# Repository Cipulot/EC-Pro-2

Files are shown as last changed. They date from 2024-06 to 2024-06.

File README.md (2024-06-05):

# EC Pro2

Open source HHKB Pro2 Controller and mainboard.

## **DEPRECATED**

Project deprecated in favor of the EC Pro X.

Please note that no further support will be provided, let alone give support for boards not sourced from my official runs or approved sources.

# EC PRO X Available for direct purchase!

If you want to buy directly and support my work you can now do it so [here](https://cannonkeys.com/products/cipulot-ec-pcbs-and-daughterboards).

## Introduction

This project is a continuation of my development of open source EC boards.

The supported layout options are the following:

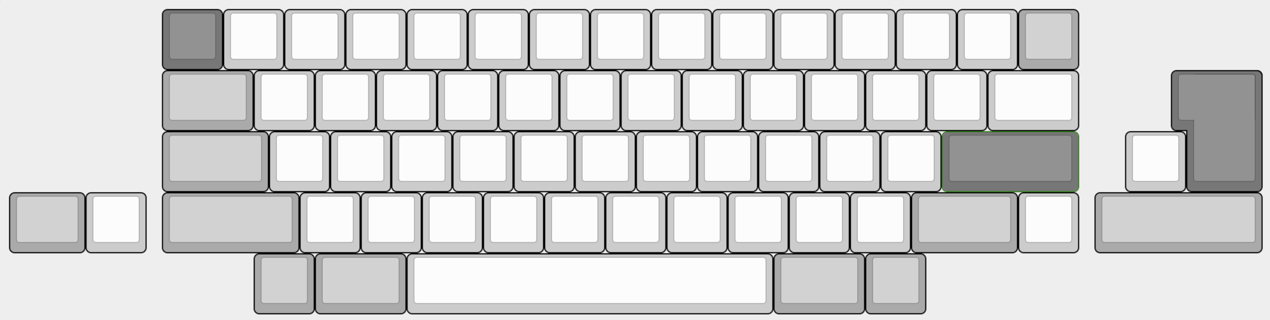
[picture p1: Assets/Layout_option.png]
Layout option


## Technical information

### Mainboard

- Layout size: HHKB Pro2 ANSI and some additions
- Compatible switches: EC switches (Topre and NIZ)
- Microcontroller: STM32F401
- Connector: JST connector for controller board
- Firmware compatibility: QMK (with VIA/VIAL support)
- Protection hardware (present on both the mainboard and both controller versions):
  - Fused
  - ESD protection

### Lite Controller board

The Lite controller board is a slimmed down version of the controller board, featuring only protection hardware and a JST connector for the mainboard.

This is cost effective choice in case the user doesn't need the USB hub feature or the aftermarket case doesn't take advantage of it.

### Normal Controller board

The Normal Controller instead is a full featured controller board, featuring a USB hub, a JST connector for the mainboard and a USB Type-C connector for the PC.

The USB hub is a USB 2.0 hub, featuring 3 USB-A 2.0 ports, one of which is internal, to be used for dongles or small USB drives.

Key features of the Normal Controller are:

- USB 2.0 hub based on the FE1.1 IC
- 2x USB-A 2.0 ports in the same position as the original HHKB Pro 2
- 1x internal USB-A 2.0 port
- Per port current limit on each downstream port using MIC2026-2 for the 2 externally accessible USB ports.

**NOTES**

- The internal USB port is intended only for low power devices, such as dongles and small usb drives as previously mentioned. It is not intended for high power devices. Furthermore it is not ESD protected nor current limited and shares the power rail with the rest of the controller.

- The main USB-C port, as well as the 2x externally accessible USB-A downstream ports are ESD protected and current limited.

Keep in mind the the USB 2.0 power budget sets a typical current limit of **500mA**, therefore that is the total budget available to the entire board (controller + mainboard + devices connected to the hub).

## Renders and Prototypes

### Render

Mainboard:

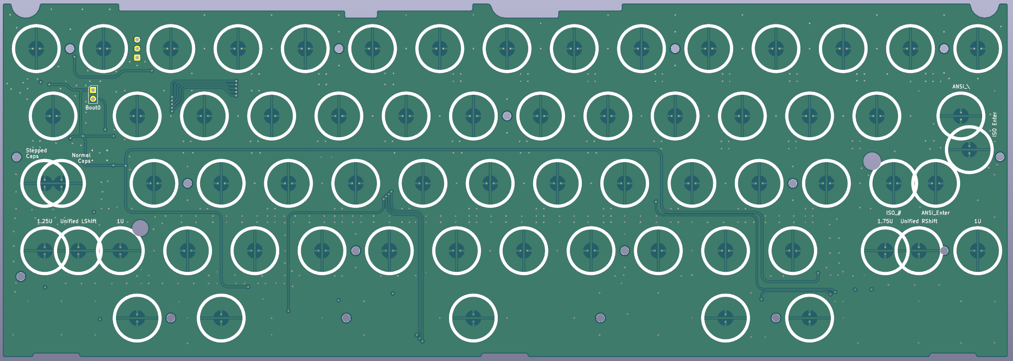
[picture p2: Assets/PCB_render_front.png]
PCB Front Render


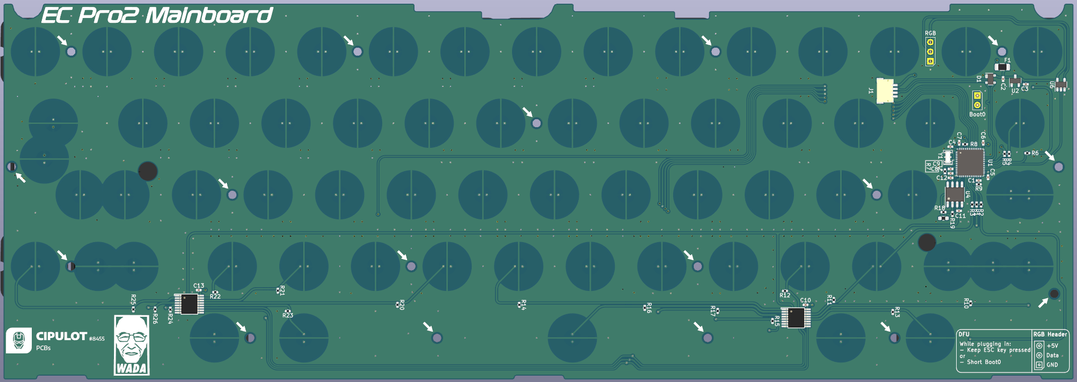
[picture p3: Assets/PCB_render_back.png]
PCB Back Render


Lite Controller board:
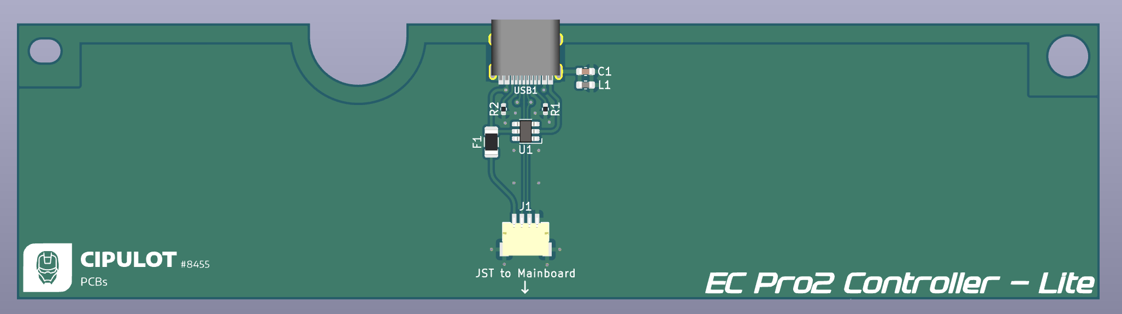
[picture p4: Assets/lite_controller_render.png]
Lite Controller Render


Normal Controller board:
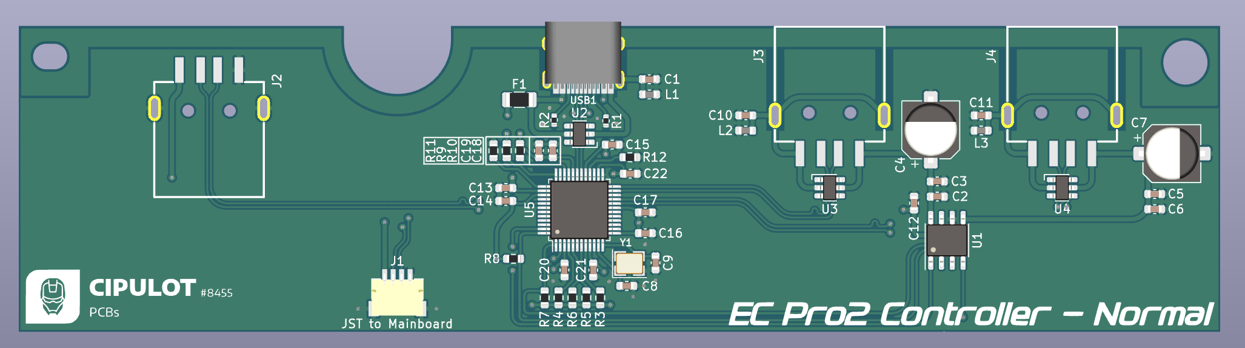
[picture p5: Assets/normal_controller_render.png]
Normal Controller Render


### Prototypes

Mainboard:

PCB Front

PCB Back

Lite Controller:
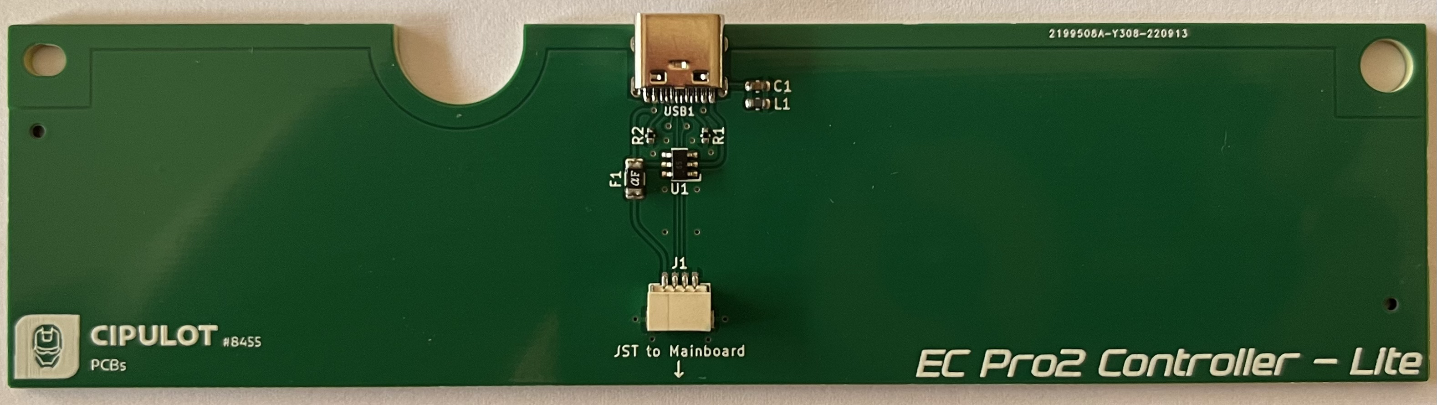
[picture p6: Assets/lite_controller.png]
Lite Controller


Normal Controller:
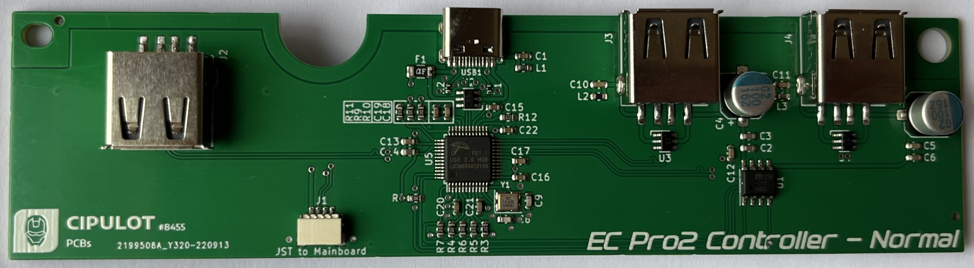
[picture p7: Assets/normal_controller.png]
Normal Controller


## Revisions and relative features

### Rev1

This revision implements all the main features of the mainboard ad controllers mentioned in the specifications.

#### Connectivity

The Revision 1 (Rev1) implements a USB hub based on the FE1.1 USB HUB IC.

Connection to the PC is achieved through a USB-C connector while devices downstream will use USB-A ports.

Mind that the USB-C connector is wider than the original USB mini connector used, therefore modifications to enlarge the port cutout on the case will be needed. In case you will use this board in an aftermarket case already designed with USB-C in mind n o further modifications are needed.

#### RGB header

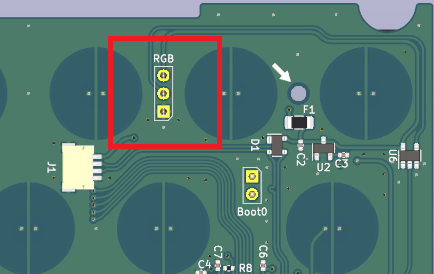
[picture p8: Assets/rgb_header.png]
RGB header


The mainboard features an RGB header for connecting +5V addressable RGB strips. THe properties of the lihting can be controlled through Vial or by assigning RGB control keycodes on the board itself.

On the bottom right corner of the PCB, near the bootloader instructions, a pinout diagram shows how to connect the strip to the header:

RGB legend

#### DFU

To access the DFU mode of the mainboard you can perform one of the following actions:

- press the key to which the `QK_BOOT` keycode is assigned (if available)
- while plugging in the board keep the `ESC` (top left corner key) pressed
- while plugging in the board short the `Boot0` pins on the mainboard

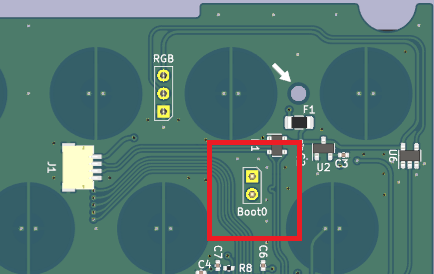
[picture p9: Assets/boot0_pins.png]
Boot0 pins


## PCB order procedure

In order to have me highers compatibility possible with PCB manufacturers, I decided to design the board around the [JLC7628 Stackup](https://cart.jlcpcb.com/impedance#:~:text=4%2DLayer%20Impedance%20Control%20Stackup) from JLCPCB.

The rational behind this is that the JCPCB stackup is relatively cheap and if the board worked with the stackup, it would be easier to get the board to work with pretty much any other many that offer an equivalent stackup and higher prices.

Both the `Lite` and `Normal` controllers can be instead be ordered with standard 2 layer stackup.

### Production files

The production can be found in the [Production folder](/Production).

As usual the `*.zip` files are the gerber files, `BOM-*.csv` are the BOM (Bill Of Material) files and `POS-*.csv` are the POS/CPL (Footprint POSition/Component Placement List) files.

## Mainboard

As mentioned above, the mainboard is designed around the JLCPCB stackup. The mainboard is a 4 layer board.

Here are the options to select when ordering the mainboard:

- PCB thickness: 1.6mm
- Impedance: NO
- Layer stackup:
  - L1(Top layer): `EC_Pro2_Mainboard-F_Cu.gbr`
  - L2(Inner layer1): `EC_Pro2_Mainboard-In1_Cu.gbr`
  - L3(Inner layer2): `EC_Pro2_Mainboard-In2_Cu.gbr`
  - L4(Bottom layer): `EC_Pro2_Mainboard-B_Cu.gbr`
- PCB Color: whatever you like
- Surface Finish: whatever you like
- Material Type: `FR-4 TG155`

All the other options can be left as default.

### Assembly options

Here follows the options to be used for assembly:

- Assembly Side: Bottom
- Tooling holes: `Added by JLCPCB`
- Confirm Parts Placement: `yes`

**USB-A connector**

An alternative part that has been tested and works is the `JINJIA USB-SMT-04F-S1-B1-R11` from [LCSC](https://www.lcsc.com/product-detail/USB-Connectors_JINJIA-USB-SMT-04F-S1-B1-R11_C718023.html).

As a general rule of thumb the USB-A connectors are interchangeable if they meet the following requirmemnts:

- fits the PCB outline
- has the same number of pins and mounting
- has the following receptor configuration

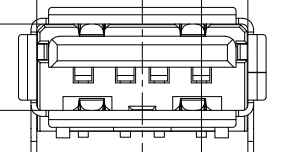
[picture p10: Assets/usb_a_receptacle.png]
USB-A receptacle
  

  To be more specific, the plastic part of the connector should be on the top and not the bottom.

  **BEWARE** that some USB-A connectors have the plastic part on the bottom, in this case the connector will have the pinout reversed, therefore causing inverse polarity on the USB lines.
  The following picture shows the correct orientation of the USB-A connector on the top board while the incorrect one on the bottom board:

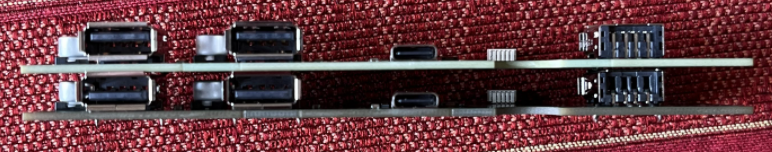
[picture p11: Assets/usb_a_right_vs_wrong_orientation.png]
USB-A orientation
  

### NOTES ABOUT THE OPTIONS

- Once you upload the gerber files wait for the system to automatically recognize the board outline and layers. It will take a while, be patient.

- `PCB thickness` has been tested on both 1.6mm and 1.2mm so it's your call on which one to use.

- For `Material Type` I strongly suggest to use `FR-4 TG155`, using the standard `FR4-Standard TG130-140` material might result in the board delamination and generally is not advised on 4 layer boards.

## Compatibility notice

The EC Pro2 project is intended as a full replacement kit for the OEM HHKB Pro2 controller and main PCB. Therefore it **IS NOT** compatible with the OEM PCBs (both controller and mainboard).

## Copyright notice

This project is not endorse nor sponsored in any way by Topre Corporation and PFU Limited. The HHKB Logo and Topre logo are trademarks of their respective owners.

## License

<br />This work is licensed under a <a rel="license" href="http://creativecommons.org/licenses/by-nc-sa/4.0/">Creative Commons Attribution-NonCommercial-ShareAlike 4.0 International License</a>.

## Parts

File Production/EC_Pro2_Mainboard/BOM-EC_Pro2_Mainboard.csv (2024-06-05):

Comment | Designator | Footprint | LCSC
1k | R19 | R_0402_1005Metric | C11702
STM32F401CBUx | U1 | QFN-48-1EP_7x7mm_P0.5mm_EP5.6x5.6mm | C118825
OPA350 | U4 | SOIC-8_3.9x4.9mm_P1.27mm | C13388
JST | J1 | JST-SR-4 | C145956
220p | C11 | C_0402_1005Metric | C1530
4.7u | C1 | C_0402_1005Metric | C23733
100 | R1,R2,R3,R4,R6 | R_0402_1005Metric | C25076
100k | R10,R11,R12,R13,R14,R15,R16,R17,R18,R20,R21,R22,R23,R24,R25,R26,R5 | R_0402_1005Metric | C25741
10k | R7,R8,R9 | R_0402_1005Metric | C25744
PRTR5V0U2X | D1 | SOT-143 | C2827688
100n | C10,C12,C13,C4,C5,C6,C7,C8 | C_0402_1005Metric | C307331
1u | C2,C3,C9 | C_0402_1005Metric | C52923
XC6206PxxxMR | U2 | SOT-23 | C5446
74HC4051 | U3,U5 | TSSOP16 | C5645
500mA | F1 | Fuse_1206_3216Metric | C70076
SN74AHCT1G125 | U6 | SOT-23-5 | C7484
8 MHz | Y1 | Resonator_SMD_Murata_CSTxExxV-3Pin_3.0x1.1mm | C907975

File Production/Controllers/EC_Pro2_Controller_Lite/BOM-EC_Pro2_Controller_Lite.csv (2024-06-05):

Comment | Designator | Footprint | LCSC
JST | J1 | JST-SR-4 | C145956
100n | C1 | C_0603_1608Metric | C14663
HRO-TYPE-C-31-M-12 | USB1 | HRO-TYPE-C-31-M-12-Assembly | C165948
5.1k | R1,R2 | R_0402_1005Metric | C25905
500mA | F1 | Fuse_1206_3216Metric | C70076
SRV05-4 | U1 | SOT-23-6-routable | C85364
220 @ 100MHz, 2A | L1 | L_0603_1608Metric | C85832

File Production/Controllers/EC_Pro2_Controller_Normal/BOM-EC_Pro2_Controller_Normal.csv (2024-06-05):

Comment | Designator | Footprint | LCSC
2.7K | R12 | R_0603_1608Metric | C13167
100u | C4,C7 | CP_Elec_6.3x5.9 | C134878
JST | J1 | JST-SR-4 | C145956
100n | C1,C10,C11,C12,C16,C17,C18,C19,C2,C20,C21,C22,C5 | C_0603_1608Metric | C14663
MIC2026-2BM | U1 | SOIC-8_3.9x4.9mm_P1.27mm | C148072
1u | C13 | C_0603_1608Metric | C15849
30p | C8,C9 | C_0603_1608Metric | C1658
HRO-TYPE-C-31-M-12 | USB1 | HRO-TYPE-C-31-M-12-Assembly | C165948
10u | C14,C15,C3,C6 | C_0603_1608Metric | C19702
10k | R10,R11,R3,R4,R5,R6,R7,R8,R9 | R_0603_1608Metric | C25804
5.1k | R1,R2 | R_0402_1005Metric | C25905
FE1.1 | U5 | LQFP-48_7x7mm_P0.5mm | C28958
500mA | F1 | Fuse_1206_3216Metric | C70076
USB_A | J2,J3,J4 | USB-SMT-04F-S1-B1-R9A | C718022
SRV05-4 | U2,U3,U4 | SOT-23-6-routable | C85364
220 @ 100MHz, 2A | L1,L2,L3 | L_0603_1608Metric | C85832
12MHz | Y1 | Crystal_SMD_3225-4pin_3.2x2.5mm | C9002

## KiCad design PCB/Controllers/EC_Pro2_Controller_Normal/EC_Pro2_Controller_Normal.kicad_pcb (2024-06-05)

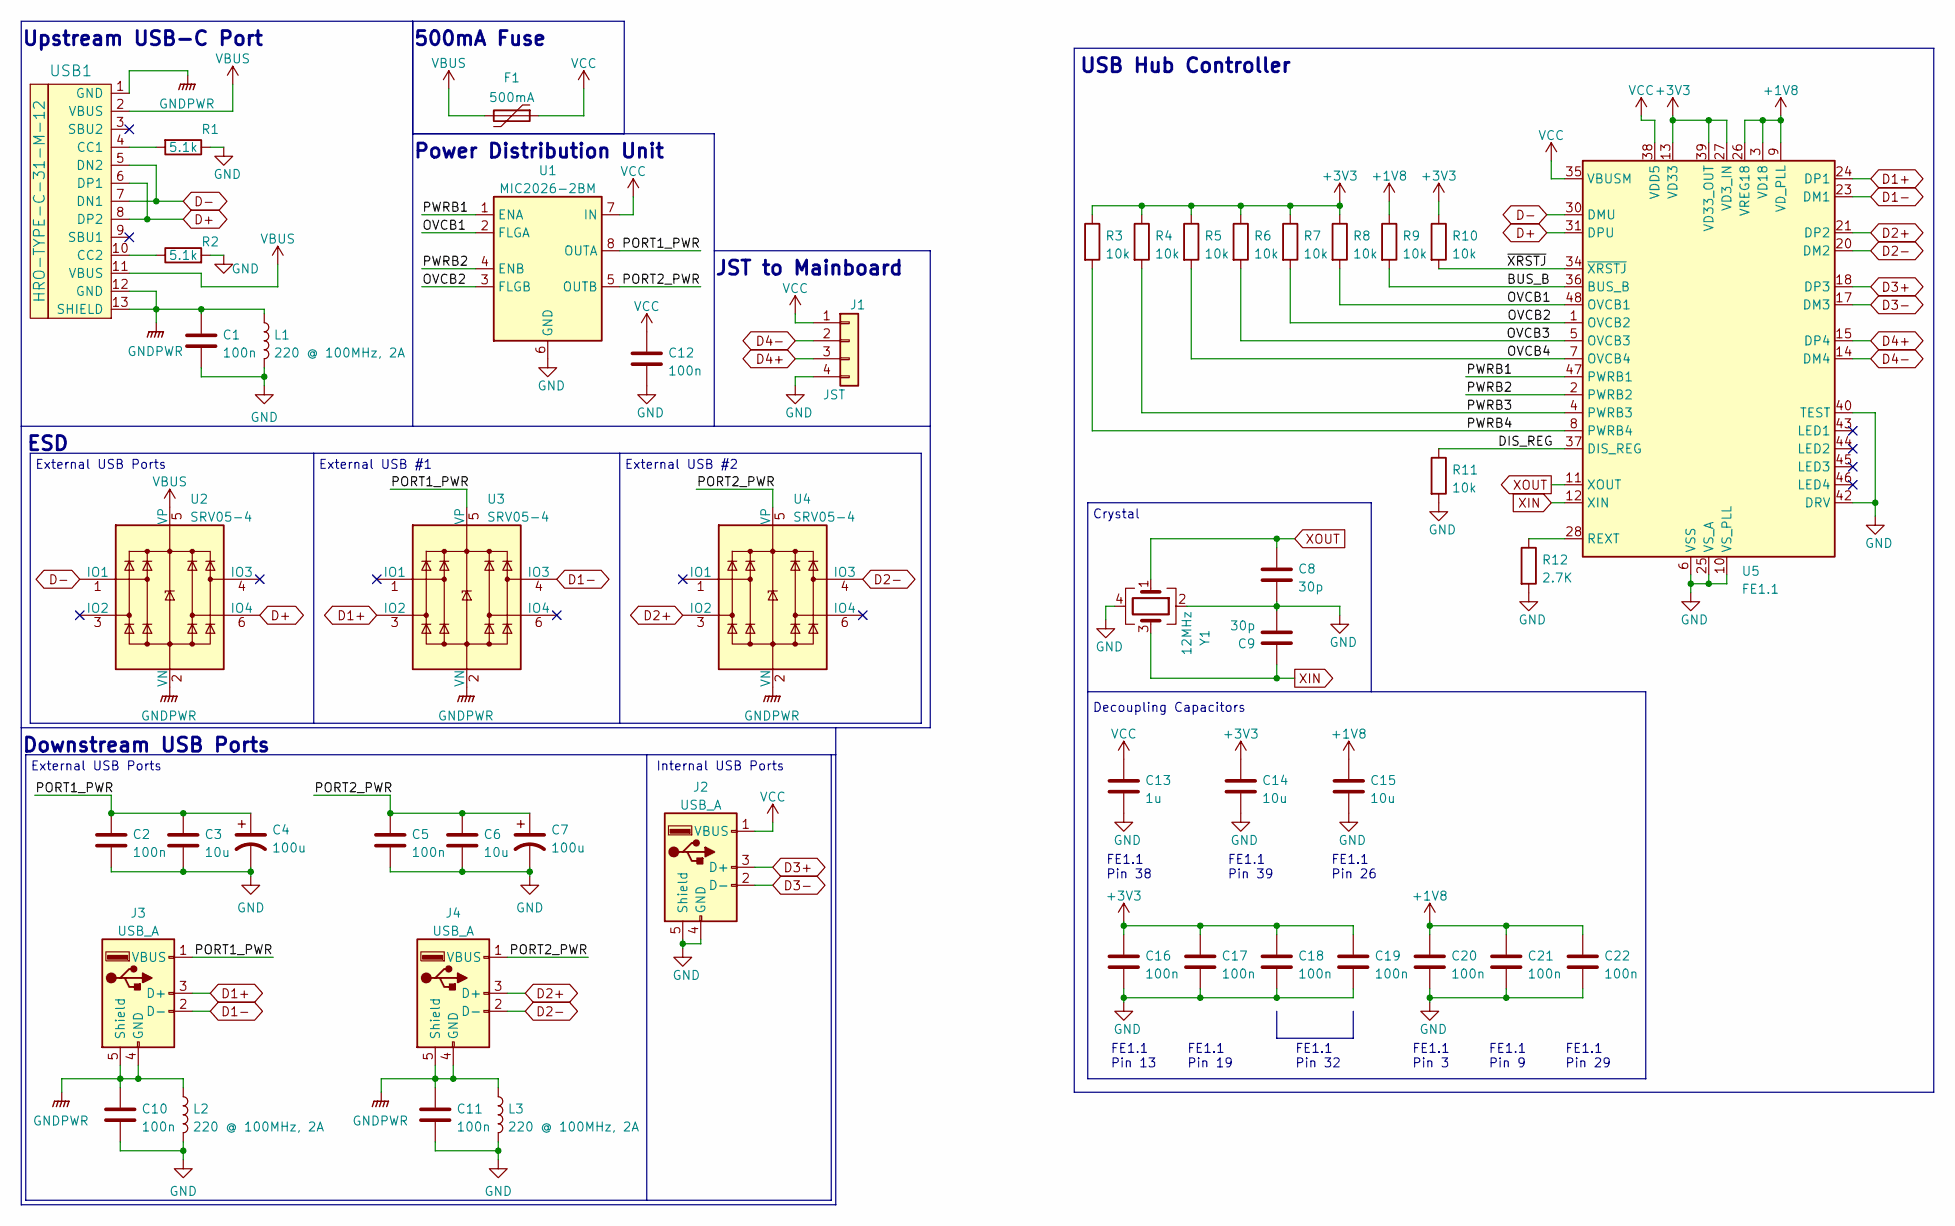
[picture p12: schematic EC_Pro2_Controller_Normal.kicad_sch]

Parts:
C1, C2, C5, C10, C11, C12, C16, C17, C18, C19, C20, C21, C22: 100n; C_0603_1608Metric; LCSC C14663
C3, C6, C14, C15: 10u; C_0603_1608Metric; LCSC C19702
C4, C7: 100u; CP_Elec_6.3x5.9; LCSC C134878
C8, C9: 30p; C_0603_1608Metric; LCSC C1658
C13: 1u; C_0603_1608Metric; LCSC C15849
F1: 500mA; Fuse_1206_3216Metric; LCSC C70076
J1: JST; JST-SR-4; LCSC C145956
J2, J3, J4: USB_A; USB-SMT-04F-S1-B1-R9A; LCSC C718022
L1, L2, L3: 220 @ 100MHz, 2A; L_0603_1608Metric; LCSC C85832
R1, R2: 5.1k; R_0402_1005Metric; LCSC C25905
R3, R4, R5, R6, R7, R8, R9, R10, R11: 10k; R_0603_1608Metric; LCSC C25804
R12: 2.7K; R_0603_1608Metric; LCSC C13167
U1: MIC2026-2BM; SOIC-8_3.9x4.9mm_P1.27mm; LCSC C148072
U2, U3, U4: SRV05-4; SOT-23-6-routable; LCSC C85364
U5: FE1.1; LQFP-48_7x7mm_P0.5mm; LCSC C28958
USB1: HRO-TYPE-C-31-M-12; HRO-TYPE-C-31-M-12-Assembly; LCSC C165948
Y1: 12MHz; Crystal_SMD_3225-4pin_3.2x2.5mm; LCSC C9002

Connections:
+1V8: C15.1, C20.1, C21.1, C22.1, R9.1, U5.3 (VD18), U5.9 (VD_PLL), U5.26 (VREG18), U5.29 (VD18)
+3V3: C14.1, C16.1, C17.1, C18.1, C19.1, R3.1, R4.1, R5.1, R6.1, R7.1, R8.1, R10.1, U5.13 (VD33), U5.19 (VD33), U5.27 (VD3_IN), U5.32 (VD33), U5.39 (VD33_OUT), U5.41 (VD33)
/BUS_B: R9.2, U5.36 (BUS_B)
/DIS_REG: R11.1, U5.37 (DIS_REG)
/OVCB1: R8.2, U1.2 (FLGA), U5.48 (OVCB1)
/OVCB2: R7.2, U1.3 (FLGB), U5.1 (OVCB2)
/OVCB3: R6.2, U5.5 (OVCB3)
/OVCB4: R5.2, U5.7 (OVCB4)
/PORT1_PWR: C2.1, C3.1, C4.1, J3.1 (VBUS), U1.8 (OUTA), U3.5 (VP)
/PORT2_PWR: C5.1, C6.1, C7.1, J4.1 (VBUS), U1.5 (OUTB), U4.5 (VP); also elsewhere on the board
/PWRB1: U1.1 (ENA), U5.47 (PWRB1)
/PWRB2: U1.4 (ENB), U5.2 (PWRB2)
/PWRB3: R4.2, U5.4 (PWRB3)
/PWRB4: R3.2, U5.8 (PWRB4)
/~XRSTJ: R10.2, U5.34 (~XRSTJ)
D1+: J3.3 (D+), U3.3 (IO2), U5.24 (DP1)
D1-: J3.2 (D-), U3.4 (IO3), U5.23 (DM1)
D2+: J4.3 (D+), U4.3 (IO2), U5.21 (DP2); also elsewhere on the board
D2-: J4.2 (D-), U4.4 (IO3), U5.20 (DM2); also elsewhere on the board
D3+: J2.3 (D+), U5.18 (DP3)
D3-: J2.2 (D-), U5.17 (DM3)
D4+: J1.3, U5.15 (DP4)
D4-: J1.2, U5.14 (DM4)
D+: U2.6 (IO4), U5.31 (DPU), USB1.6 (DP1), USB1.8 (DP2)
D-: U2.1 (IO1), U5.30 (DMU), USB1.5 (DN2), USB1.7 (DN1)
GND: C1.2, C2.2, C3.2, C4.2, C5.2, C6.2, C7.2, C8.2, C9.2, C10.2, C11.2, C12.2, C13.2, C14.2, C15.2, C16.2, C17.2, C18.2, C19.2, C20.2, C21.2, C22.2, J1.4, J2.4 (GND), J2.5 (Shield), L1.2, L2.2, L3.2, R1.1, R2.2, R11.2, R12.2, U1.6 (GND), U5.6 (VSS), U5.10 (VS_PLL), U5.16 (VSS), U5.22 (VSS), U5.25 (VS_A), U5.33 (VSS), U5.40 (TEST), U5.42 (DRV), Y1.2, Y1.4
GNDPWR: C1.1, C10.1, C11.1, J3.4 (GND), J3.5 (Shield), J4.4 (GND), J4.5 (Shield), L1.1, L2.1, L3.1, U2.2 (VN), U3.2 (VN), U4.2 (VN), USB1.1 (GND), USB1.12 (GND), USB1.13 (SHIELD); also elsewhere on the board
unnamed: R1.2, USB1.4 (CC1)
unnamed: R2.1, USB1.10 (CC2)
unnamed: R12.1, U5.28 (REXT)
VBUS: F1.2, U2.5 (VP), USB1.2 (VBUS), USB1.11 (VBUS)
VCC: C12.1, C13.1, F1.1, J1.1, J2.1 (VBUS), U1.7 (IN), U5.35 (VBUSM), U5.38 (VDD5)
XIN: C9.1, U5.12 (XIN), Y1.3
XOUT: C8.1, U5.11 (XOUT), Y1.1

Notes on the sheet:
Decoupling Capacitors
Upstream USB-C Port
Internal USB Ports
Downstream USB Ports
External USB #2
ESD
FE1.1 Pin 32
External USB #1
FE1.1 Pin 38
FE1.1 Pin 39
Power Distribution Unit
FE1.1 Pin 9
FE1.1 Pin 3
Crystal
FE1.1 Pin 13
FE1.1 Pin 29
External USB Ports
JST to Mainboard
FE1.1 Pin 19
FE1.1 Pin 26
USB Hub Controller
500mA Fuse

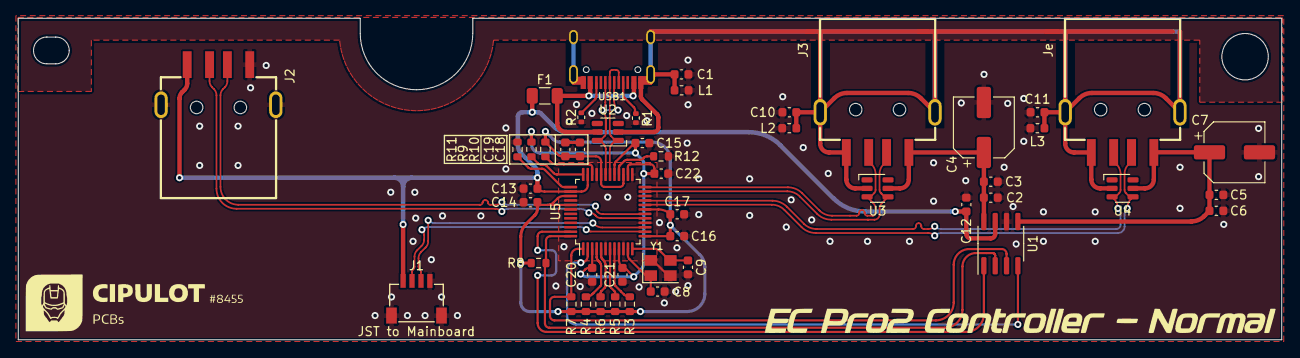
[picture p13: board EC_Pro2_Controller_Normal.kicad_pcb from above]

Board: 2 copper layers, 141.5 x 36.0 mm, 49 parts (0 on the bottom side), 34 nets.

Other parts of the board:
Je: USB_A; USB-SMT-04F-S1-B1-R9A

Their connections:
/PORT2_PWR: Je.1 (VBUS); also elsewhere on the board
D2+: Je.3 (D+); also elsewhere on the board
D2-: Je.2 (D-); also elsewhere on the board
GNDPWR: Je.4 (GND), Je.5 (Shield); also elsewhere on the board

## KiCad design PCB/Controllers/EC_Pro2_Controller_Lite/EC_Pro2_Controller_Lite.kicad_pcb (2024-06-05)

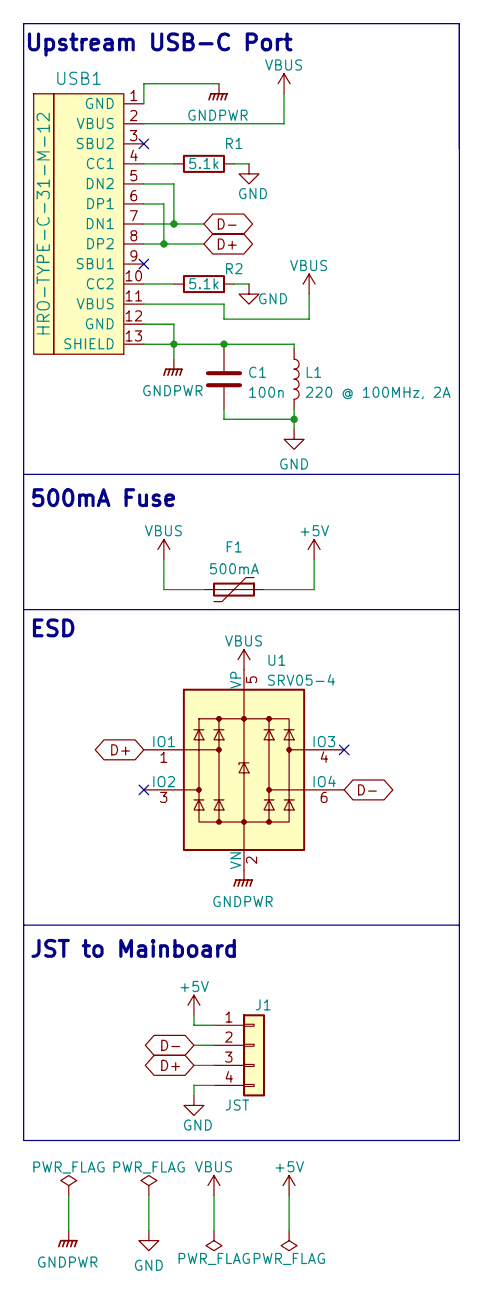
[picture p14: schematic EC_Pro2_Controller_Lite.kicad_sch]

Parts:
C1: 100n; C_0603_1608Metric; LCSC C14663
F1: 500mA; Fuse_1206_3216Metric; LCSC C70076
J1: JST; JST-SR-4; LCSC C145956
L1: 220 @ 100MHz, 2A; L_0603_1608Metric; LCSC C85832
R1, R2: 5.1k; R_0402_1005Metric; LCSC C25905
U1: SRV05-4; SOT-23-6-routable; LCSC C85364
USB1: HRO-TYPE-C-31-M-12; HRO-TYPE-C-31-M-12-Assembly; LCSC C165948

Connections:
+5V: F1.1, J1.1
D+: J1.3, U1.1 (IO1), USB1.6 (DP1), USB1.8 (DP2)
D-: J1.2, U1.6 (IO4), USB1.5 (DN2), USB1.7 (DN1)
GND: C1.2, J1.4, L1.2, R1.1, R2.2
GNDPWR: C1.1, L1.1, U1.2 (VN), USB1.1 (GND), USB1.12 (GND), USB1.13 (SHIELD)
unnamed: R1.2, USB1.4 (CC1)
unnamed: R2.1, USB1.10 (CC2)
VBUS: F1.2, U1.5 (VP), USB1.2 (VBUS), USB1.11 (VBUS)

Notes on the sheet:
500mA Fuse
Upstream USB-C Port
ESD
JST to Mainboard

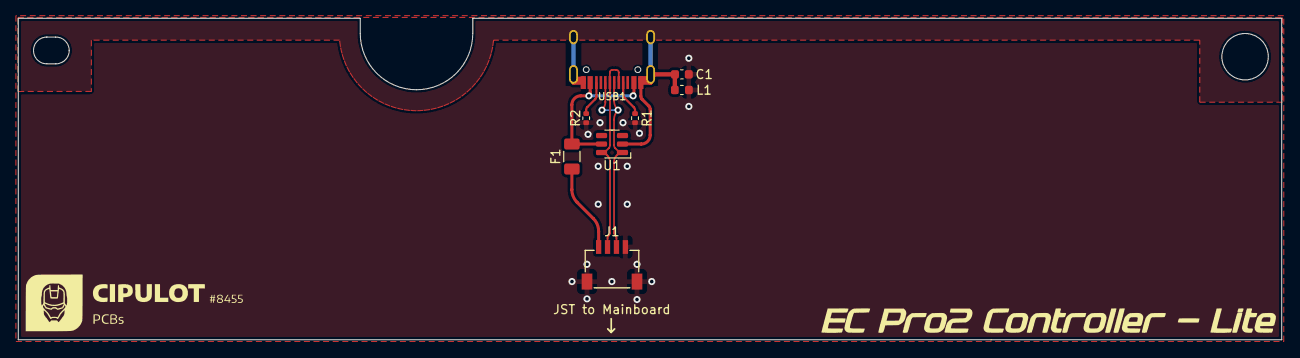
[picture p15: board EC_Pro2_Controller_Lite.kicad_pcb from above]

Board: 2 copper layers, 141.5 x 36.0 mm, 8 parts (0 on the bottom side), 8 nets.

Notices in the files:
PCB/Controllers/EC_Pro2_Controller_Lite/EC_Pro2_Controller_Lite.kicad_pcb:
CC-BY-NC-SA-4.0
